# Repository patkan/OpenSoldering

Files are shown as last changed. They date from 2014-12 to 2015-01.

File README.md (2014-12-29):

OpenSoldering
=============

###Kurzbeschreibung
OpenSource Lötstation mit (hoffentlich mal) Unterstützung für verschiedene JBC-, Weller- und Ersa-Lötkolben

###Aufbau
Modular. Kommunikation über RS485 mit dem SB9-Bussystem

###Ziel
eine OpenSource Lötstation mit Basisstation und einzelnen Satellitenstationen, die jeweils ein Lötgerät (Kolben, Zange, Pinzette) ansteuern. Auch geeignet für Gruppen oder Werkstätten, die mehrere Lötplätze brauchen.

###Status Quo
- Modul für den JBC-Lötkolben T245A in Entwicklung.
- Thermospannung im Arbeitspunkt für C245 Kartusche 4,2mV; Aufnahme der Kennlinie fehlt noch.

###TODOs
- Aufbau und ausführliche Tests am Lötkolben, Programmierung der PI-Regelung mit Vorsteuerung, (vermutlich kein PID-Konzept nötig) und Bau der Kontrollstation.
- Planung für ein Weller-Modul für die modernen Lötspitzen des WXMP-Lötkolbens, die einen einfachen und günstigen Lötkolben versprechen.
- Planung der Kontrollstation:
	* Display: OLED? gLCD?
	* Eingabe: Drehknopf? Touchscreen?
	* zusätzliche Konnektivität: IoT? Bluetooth? Lötrauchabsaugung?
	* Reglerprofile: Optimierung auf Ausregelzeit/minimale Überschwingung?

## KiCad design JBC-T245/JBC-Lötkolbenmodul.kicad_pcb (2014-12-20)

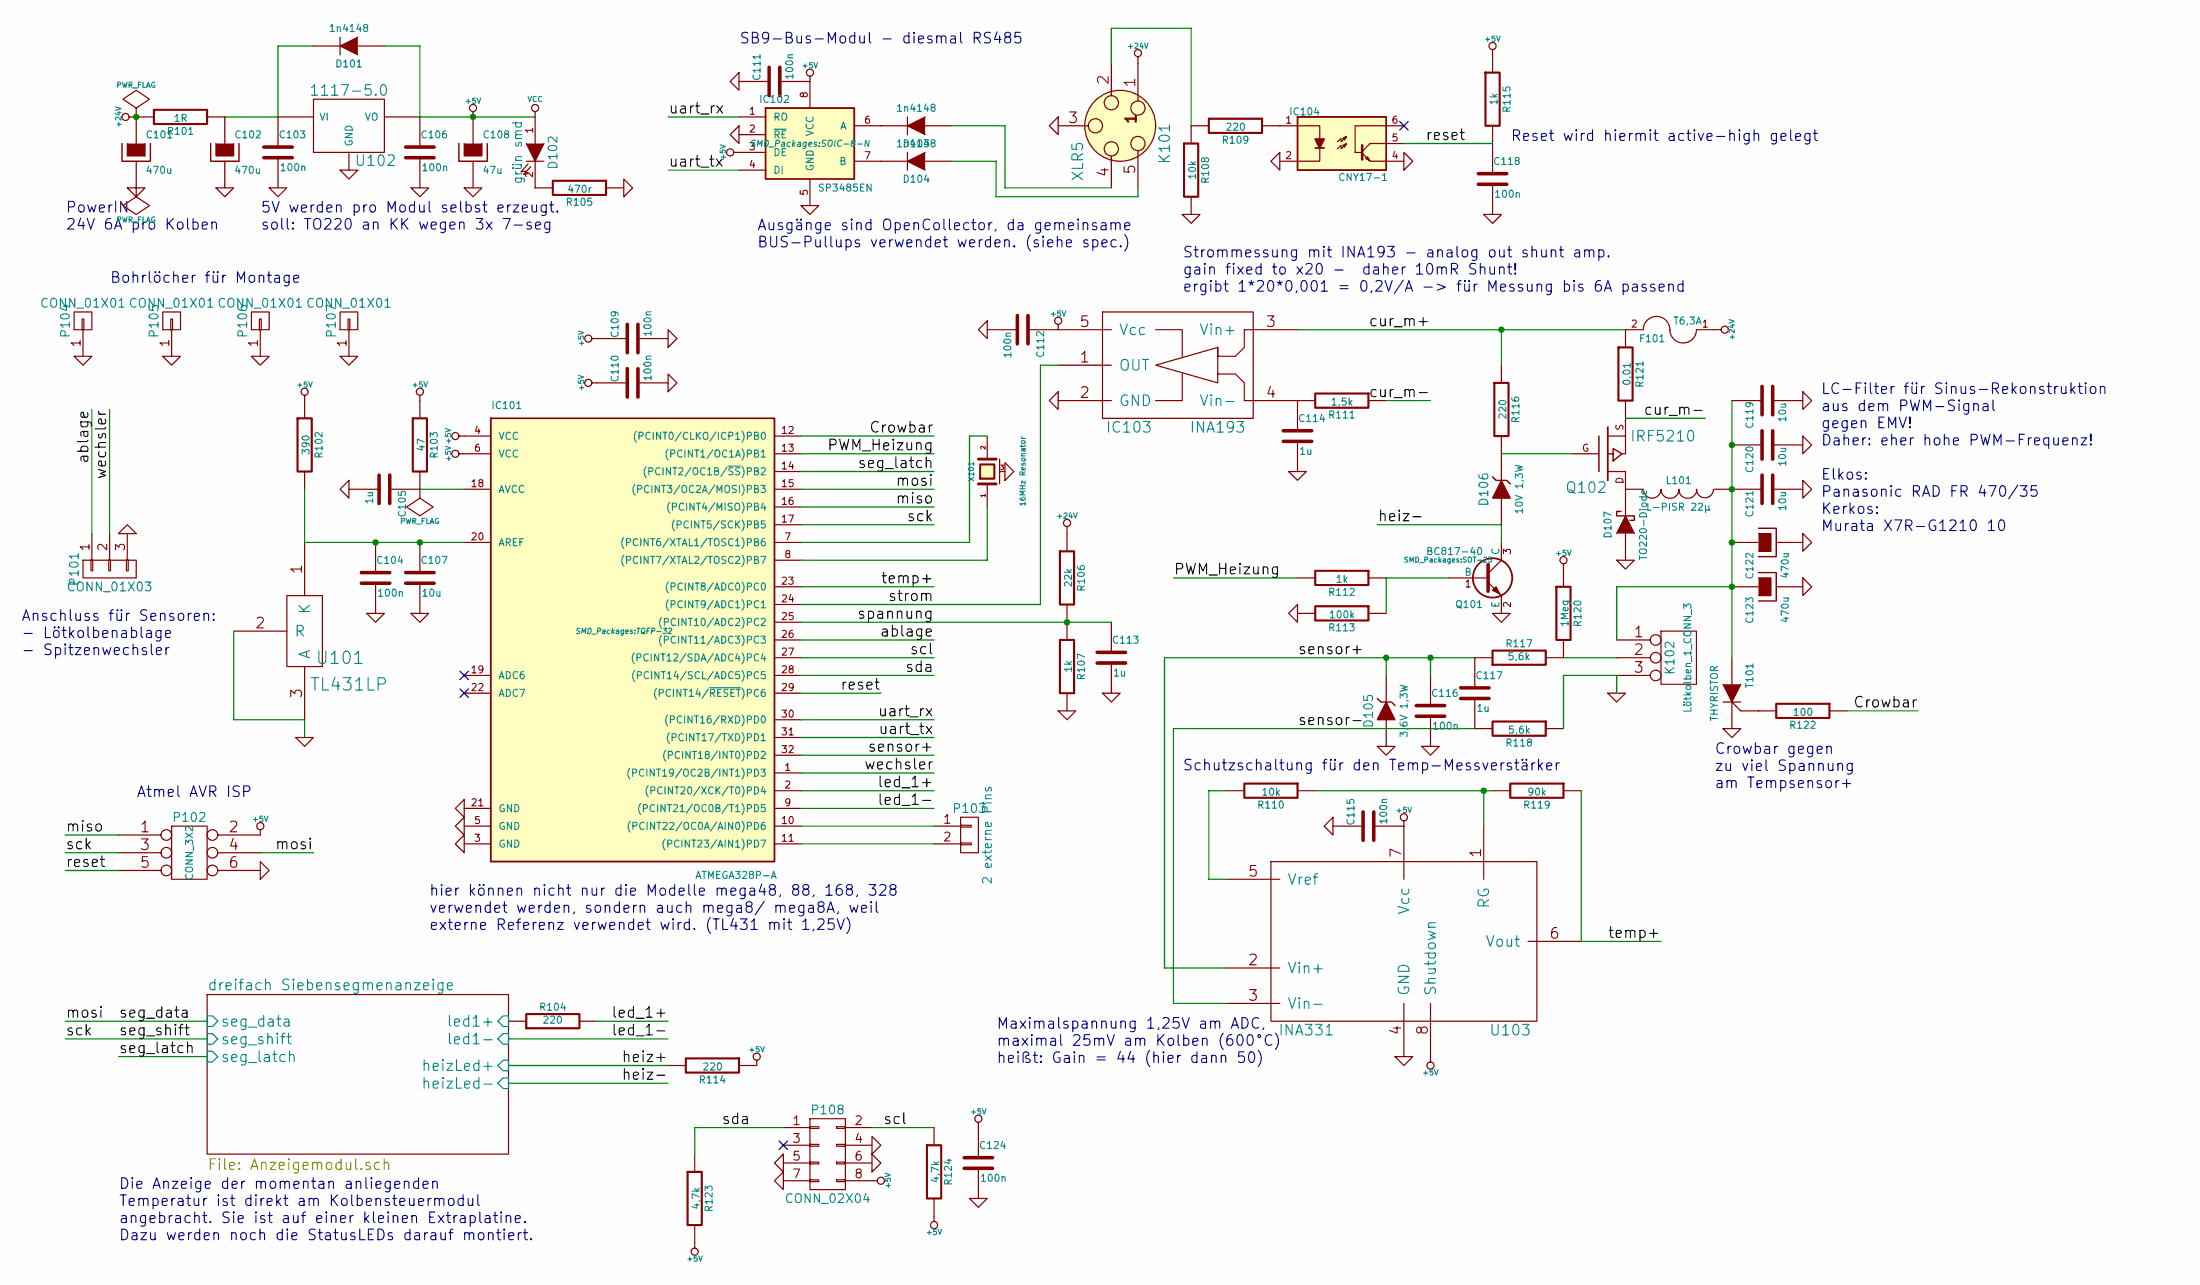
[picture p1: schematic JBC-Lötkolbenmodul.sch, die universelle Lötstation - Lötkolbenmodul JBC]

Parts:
C101, C102, C122, C123: 470u; Elko_vert_DM8_RM3-5_CopperClear
C103, C104, C106, C109, C110, C111, C112, C115, C116, C118, C124: 100n; C_0805
C105, C113, C114, C117: 1u; C_0805
C107: 10u; C_0805
C108: 47u; C_1210
C119, C120, C121: 10u; C_1210
D101, D103, D104: 1n4148; Diode-MiniMELF_Standard
D102: grün smd; LED-0805
D105: 3,6V 1,3W; Diode_DO-41_SOD81_Horizontal_RM10
D106: 10V 1,3W; Diode_DO-41_SOD81_Horizontal_RM10
D107: TO220-Diode; TO-220_Neutral123_Vertical
F101: T6,3A; Fuseholder5x20_Horizontal_closed_Bulgin_FX0457
IC101: ATMEGA328P-A; TQFP-32
IC102: SP3485EN; SOIC-8-N
IC103: INA193; SOT-23-5
IC104: CNY17-1; DIP-6__300_ELL
K101: XLR5; Pin_Header_Straight_1x05
K102: Lötkolben_1_CONN_3; Pin_Header_Straight_1x03
L101: L-PISR 22µ; L_Fastron_PISR
P101: CONN_01X03; Pin_Header_Straight_1x03
P102: CONN_3X2; Pin_Header_Straight_2x03
P103: 2 externe Pins; Pin_Header_Straight_1x02
P104, P105, P106, P107: CONN_01X01; 1pin
P108: CONN_02X04; SOIC-8-N
Q101: BC817-40; SOT-23
Q102: IRF5210; DPAK-3_GDS
R101: 1R; R_0603
R102: 390; R_0603
R103: 47; R_0603
R104, R109, R114, R116: 220; R_0603
R105: 470r; R_0603
R106: 22k; R_0603
R107, R112, R115: 1k; R_0603
R108, R110: 10k; R_0603
R111: 1,5k; R_0603
R113: 100k; R_0603
R117, R118: 5,6k; R_0603
R119: 90k; R_0603
R120: 1Meg; R_0603
R121: 0,01; R_1210
R122: 100; R_0603
R123, R124: 4,7k; R_0603
T101: THYRISTOR; TO-220_Neutral123_Vertical
U101: TL431LP; SOIC-8-N
U102: 1117-5.0; TO-220_Neutral123_Vertical
U103: INA331; SSOP-8
X101: 16MHz Resonator; CerOsc_3,2x1,3

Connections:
+24V: C101.1, F101.1, K101.1, R101.2, R106.1
/Crowbar: IC101.12 ((PCINT0/CLKO/ICP1)PB0), R122.1
/PWM_Heizung: IC101.13 ((PCINT1/OC1A)PB1), R112.2
/ablage: IC101.26 ((PCINT11/ADC3)PC3), P101.1
/cur_m+: F101.2, IC103.3 (Vin+), R116.1, R121.1
/cur_m-: Q102.S, R111.1, R121.2
/dreifach Siebensegmenanzeige/heizLed+: R114.2; also elsewhere on the board
/dreifach Siebensegmenanzeige/heizLed-: D106.1 (A), Q101.3 (C); also elsewhere on the board
/dreifach Siebensegmenanzeige/led1+: R104.1; also elsewhere on the board
/dreifach Siebensegmenanzeige/led1-: IC101.9 ((PCINT21/OC0B/T1)PD5); also elsewhere on the board
/dreifach Siebensegmenanzeige/seg_data: IC101.15 ((PCINT3/OC2A/MOSI)PB3), P102.4; also elsewhere on the board
/dreifach Siebensegmenanzeige/seg_latch: IC101.14 ((PCINT2/OC1B/~SS~)PB2); also elsewhere on the board
/dreifach Siebensegmenanzeige/seg_shift: IC101.17 ((PCINT5/SCK)PB5), P102.3; also elsewhere on the board
/led_1+: IC101.2 ((PCINT20/XCK/T0)PD4), R104.2
/miso: IC101.16 ((PCINT4/MISO)PB4), P102.1
/reset: C118.1, IC101.29 ((PCINT14/~RESET~)PC6), IC104.5, P102.5, R115.2
/scl: IC101.27 ((PCINT12/SDA/ADC4)PC4), P108.2, R124.1
/sda: IC101.28 ((PCINT14/SCL/ADC5)PC5), P108.1, R123.1
/sensor+: C116.1, C117.1, D105.2 (K), IC101.32 ((PCINT18/INT0)PD2), R117.1, U103.2 (Vin+)
/sensor-: C117.2, R118.2, U103.3 (Vin-)
/spannung: C113.1, IC101.25 ((PCINT10/ADC2)PC2), R106.2, R107.1
/strom: IC101.24 ((PCINT9/ADC1)PC1), IC103.1 (OUT)
/temp+: IC101.23 ((PCINT8/ADC0)PC0), R119.1, U103.6 (Vout)
/uart_rx: IC101.30 ((PCINT16/RXD)PD0), IC102.1 (RO)
/uart_tx: IC101.31 ((PCINT17/TXD)PD1), IC102.4 (DI)
/wechsler: IC101.1 ((PCINT19/OC2B/INT1)PD3), P101.2
unnamed: C102.1, C103.1, D101.2 (K), R101.1, U102.VI
unnamed: C104.1, C107.1, IC101.20 (AREF), R102.2, U101.1 (K)
unnamed: C105.1, IC101.18 (AVCC), R103.2
unnamed: C114.1, IC103.4 (Vin-), R111.2
unnamed: C119.1, C120.1, C121.1, C122.1, C123.1, K102.1, L101.1, T101.A
unnamed: D102.2 (K), R105.2
unnamed: D103.1 (A), K101.4 (P3)
unnamed: D103.2 (K), IC102.6 (A)
unnamed: D104.1 (A), K101.5
unnamed: D104.2 (K), IC102.7 (B)
unnamed: D106.2 (K), Q102.G, R116.2
unnamed: D107.2 (K), L101.2, Q102.D
unnamed: IC101.7 ((PCINT6/XTAL1/TOSC1)PB6), X101.2
unnamed: IC101.8 ((PCINT7/XTAL2/TOSC2)PB7), X101.1
unnamed: IC101.10 ((PCINT22/OC0A/AIN0)PD6), P103.1
unnamed: IC101.11 ((PCINT23/AIN1)PD7), P103.2
unnamed: IC104.1, R109.1
unnamed: K101.2, R108.1, R109.2
unnamed: K102.2 (PM), R117.2, R120.2
unnamed: Q101.1 (B), R112.1, R113.1
unnamed: R110.1, R119.2, U103.1 (RG)
unnamed: R110.2, U103.5 (Vref)
unnamed: R122.2, T101.G

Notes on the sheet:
Atmel AVR ISP
PowerIN 24V 6A pro Kolben
Crowbar gegen zu viel Spannung am Tempsensor+
Schutzschaltung für den Temp-Messverstärker
SB9-Bus-Modul - diesmal RS485
Ausgänge sind OpenCollector, da gemeinsame BUS-Pullups verwendet werden. (siehe spec.)
5V werden pro Modul selbst erzeugt. soll: TO220 an KK wegen 3x 7-seg
Anschluss für Sensoren: - Lötkolbenablage - Spitzenwechsler
LC-Filter für Sinus-Rekonstruktion aus dem PWM-Signal gegen EMV! Daher: eher hohe PWM-Frequenz! Elkos: Panasonic RAD FR 470/35 Kerkos: Murata X7R-G1210 10
Strommessung mit INA193 - analog out shunt amp. gain fixed to x20 - daher 10mR Shunt! ergibt 1*20*0,001 = 0,2V/A -> für Messung bis 6A passend
Die Anzeige der momentan anliegenden Temperatur ist direkt am Kolbensteuermodul angebracht. Sie ist auf einer kleinen Extraplatine. Dazu werden noch die StatusLEDs darauf montiert.
Maximalspannung 1,25V am ADC, maximal 25mV am Kolben (600°C) heißt: Gain = 44 (hier dann 50)
Reset wird hiermit active-high gelegt
hier können nicht nur die Modelle mega48, 88, 168, 328 verwendet werden, sondern auch mega8/ mega8A, weil externe Referenz verwendet wird. (TL431 mit 1,25V)
Bohrlöcher für Montage

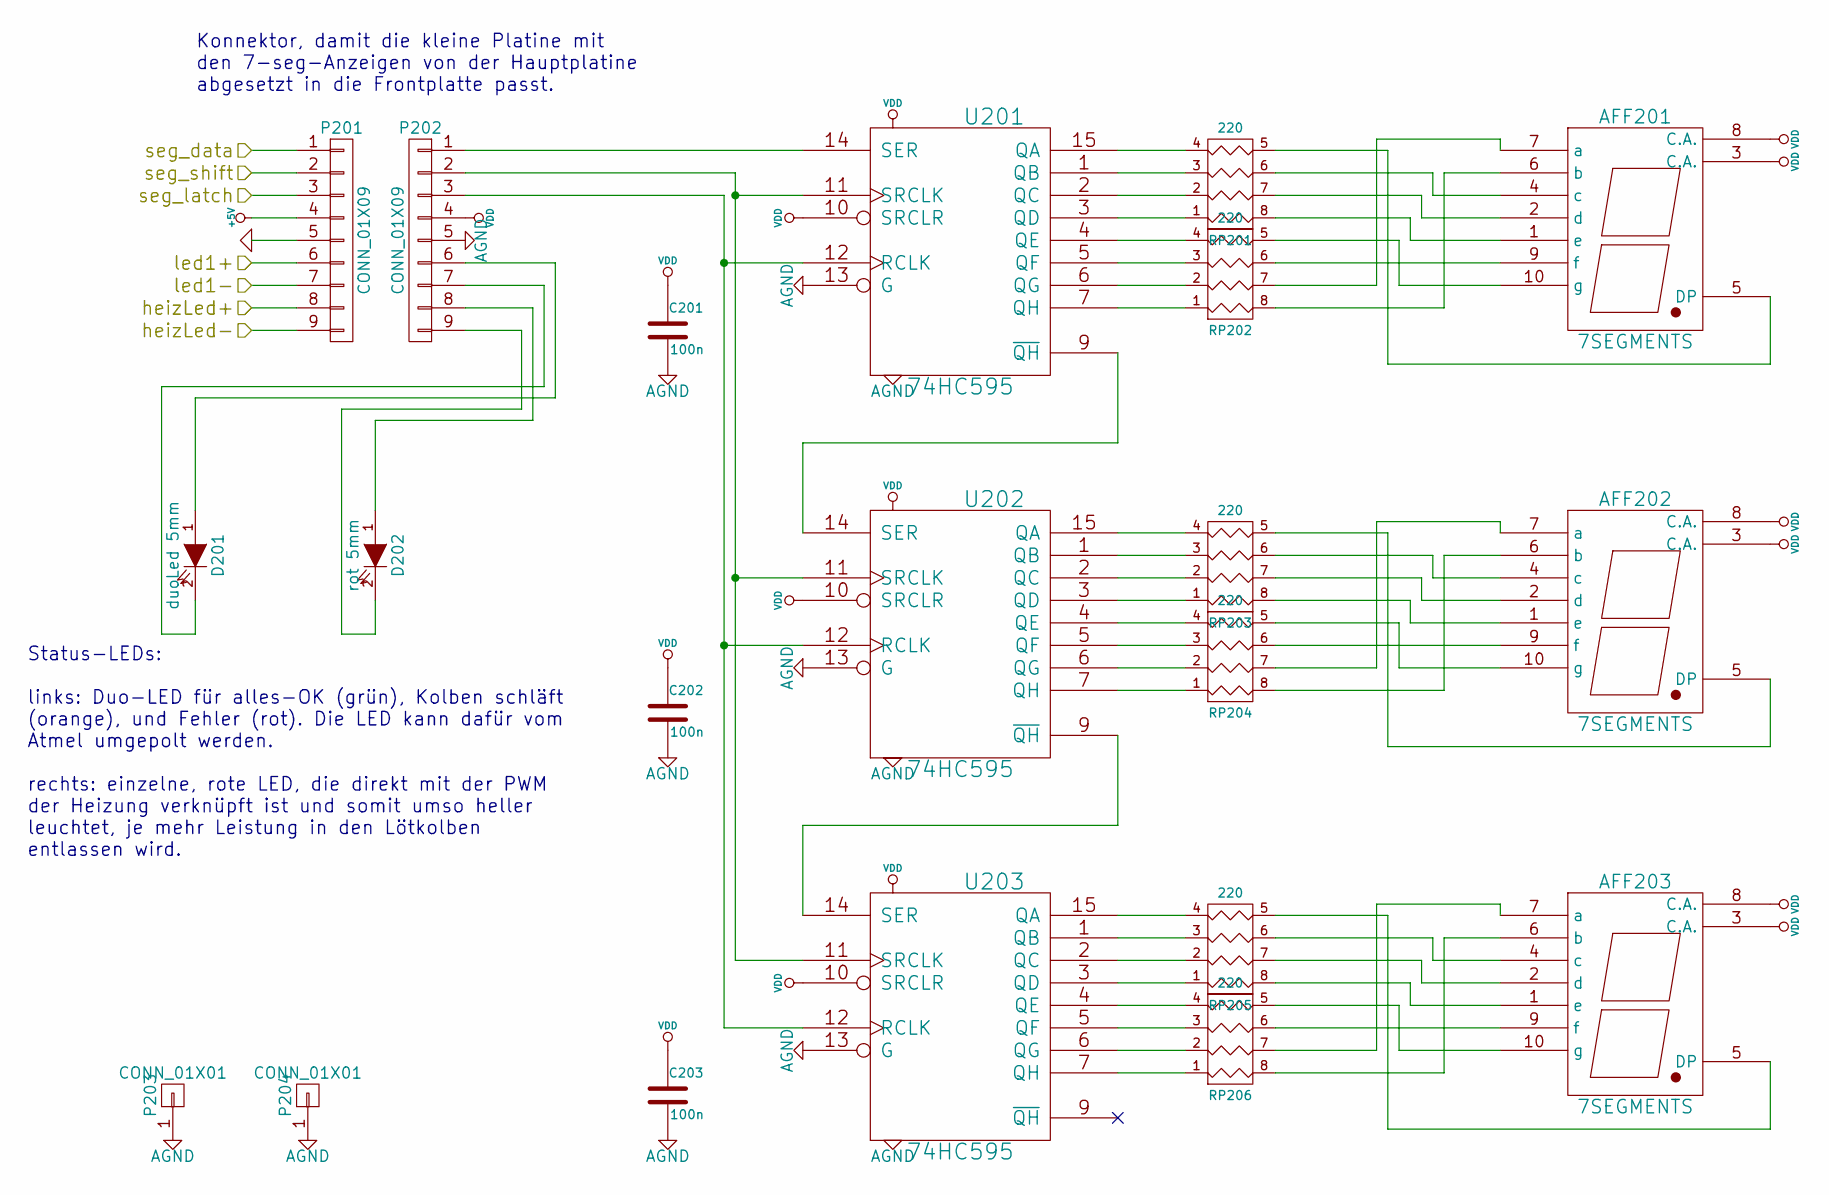
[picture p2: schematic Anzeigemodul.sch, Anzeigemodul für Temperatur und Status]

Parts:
AFF201, AFF202, AFF203: 7SEGMENTS; DIP-10__300_ELL
C201, C202, C203: 100n; C_0805
D201: duoLed 5mm; LED-5MM
D202: rot 5mm; LED-5MM
P201: CONN_01X09; Pin_Header_Straight_1x09
P202: CONN_01X09; Pin_Header_Angled_1x09
P203, P204: CONN_01X01; 1pin
RP201, RP202, RP203, RP204, RP205, RP206: 220; R_Cat16-4
U201, U202, U203: 74HC595; SO-16-N

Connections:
/dreifach Siebensegmenanzeige/heizLed+: P201.8; also elsewhere on the board
/dreifach Siebensegmenanzeige/heizLed-: P201.9; also elsewhere on the board
/dreifach Siebensegmenanzeige/led1+: P201.6; also elsewhere on the board
/dreifach Siebensegmenanzeige/led1-: P201.7; also elsewhere on the board
/dreifach Siebensegmenanzeige/seg_data: P201.1; also elsewhere on the board
/dreifach Siebensegmenanzeige/seg_latch: P201.3; also elsewhere on the board
/dreifach Siebensegmenanzeige/seg_shift: P201.2; also elsewhere on the board
unnamed: AFF201.1 (e), RP201.8 (R1)
unnamed: AFF201.2 (d), RP201.7 (R2)
unnamed: AFF201.4 (c), RP201.6 (R3)
unnamed: AFF201.5 (DP), RP201.5 (R4)
unnamed: AFF201.6 (b), RP202.8 (R1)
unnamed: AFF201.7 (a), RP202.7 (R2)
unnamed: AFF201.9 (f), RP202.6 (R3)
unnamed: AFF201.10 (g), RP202.5 (R4)
unnamed: AFF202.1 (e), RP203.8 (R1)
unnamed: AFF202.2 (d), RP203.7 (R2)
unnamed: AFF202.4 (c), RP203.6 (R3)
unnamed: AFF202.5 (DP), RP203.5 (R4)
unnamed: AFF202.6 (b), RP204.8 (R1)
unnamed: AFF202.7 (a), RP204.7 (R2)
unnamed: AFF202.9 (f), RP204.6 (R3)
unnamed: AFF202.10 (g), RP204.5 (R4)
unnamed: AFF203.1 (e), RP205.8 (R1)
unnamed: AFF203.2 (d), RP205.7 (R2)
unnamed: AFF203.4 (c), RP205.6 (R3)
unnamed: AFF203.5 (DP), RP205.5 (R4)
unnamed: AFF203.6 (b), RP206.8 (R1)
unnamed: AFF203.7 (a), RP206.7 (R2)
unnamed: AFF203.9 (f), RP206.6 (R3)
unnamed: AFF203.10 (g), RP206.5 (R4)
unnamed: D201.1 (A), P202.6
unnamed: D201.2 (K), P202.7
unnamed: D202.1 (A), P202.8
unnamed: D202.2 (K), P202.9
unnamed: P202.1, U201.14 (SER)
unnamed: P202.2, U201.11 (SRCLK), U202.11 (SRCLK), U203.11 (SRCLK)
unnamed: P202.3, U201.12 (RCLK), U202.12 (RCLK), U203.12 (RCLK)
unnamed: RP201.1, U201.3 (QD)
unnamed: RP201.2, U201.2 (QC)
unnamed: RP201.3, U201.1 (QB)
unnamed: RP201.4, U201.15 (QA)
unnamed: RP202.1, U201.7 (QH)
unnamed: RP202.2, U201.6 (QG)
unnamed: RP202.3, U201.5 (QF)
unnamed: RP202.4, U201.4 (QE)
unnamed: RP203.1, U202.3 (QD)
unnamed: RP203.2, U202.2 (QC)
unnamed: RP203.3, U202.1 (QB)
unnamed: RP203.4, U202.15 (QA)
unnamed: RP204.1, U202.7 (QH)
unnamed: RP204.2, U202.6 (QG)
unnamed: RP204.3, U202.5 (QF)
unnamed: RP204.4, U202.4 (QE)
unnamed: RP205.1, U203.3 (QD)
unnamed: RP205.2, U203.2 (QC)
unnamed: RP205.3, U203.1 (QB)
unnamed: RP205.4, U203.15 (QA)
unnamed: RP206.1, U203.7 (QH)
unnamed: RP206.2, U203.6 (QG)
unnamed: RP206.3, U203.5 (QF)
unnamed: RP206.4, U203.4 (QE)
unnamed: U201.9 (~QH), U202.14 (SER)
unnamed: U202.9 (~QH), U203.14 (SER)

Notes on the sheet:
Konnektor, damit die kleine Platine mit den 7-seg-Anzeigen von der Hauptplatine abgesetzt in die Frontplatte passt.
Status-LEDs: links: Duo-LED für alles-OK (grün), Kolben schläft (orange), und Fehler (rot). Die LED kann dafür vom Atmel umgepolt werden. rechts: einzelne, rote LED, die direkt mit der PWM der Heizung verknüpft ist und somit umso heller leuchtet, je mehr Leistung in den Lötkolben entlassen wird.

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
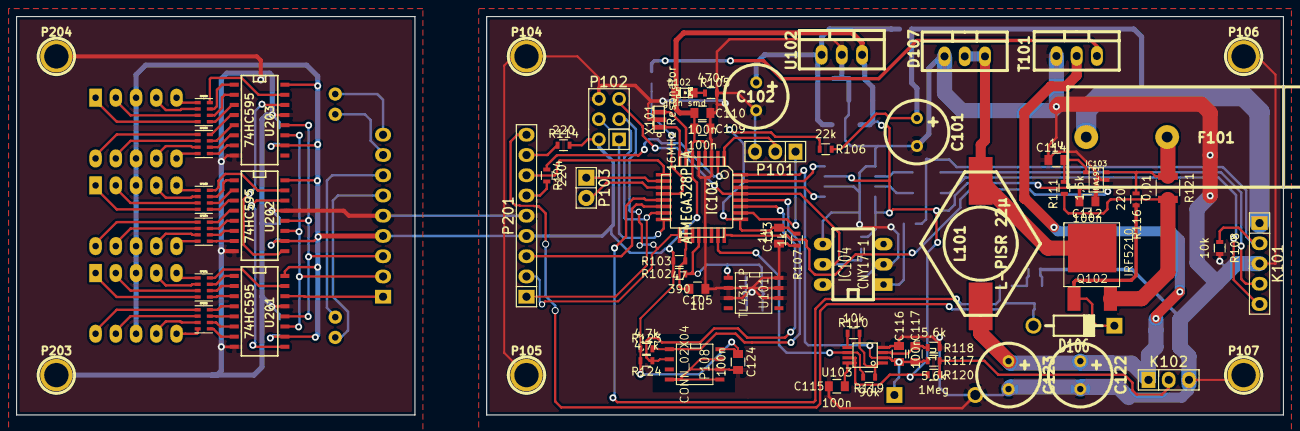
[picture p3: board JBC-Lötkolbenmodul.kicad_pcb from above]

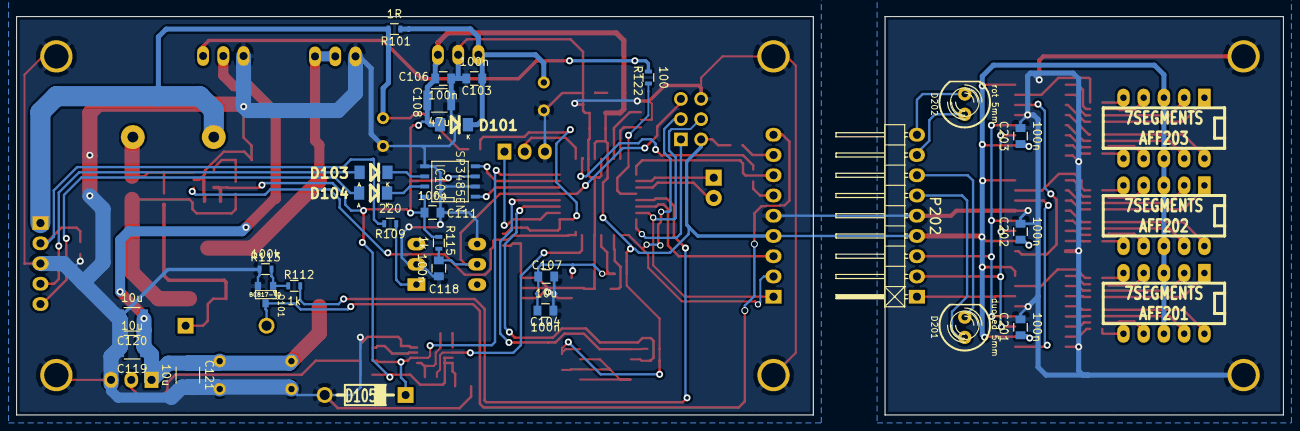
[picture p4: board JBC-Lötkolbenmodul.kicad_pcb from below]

Board: 2 copper layers, 159.0 x 50.0 mm, 99 parts (31 on the bottom side), 108 nets.

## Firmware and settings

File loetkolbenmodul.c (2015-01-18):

/*
 *    Filename: loetkobenmodul.c
 *     Version: 0.0.4
 * Description: Ansteuerung eines JBC T245A Lötkolbens
 *     License: GPLv3 or later
 *     Depends: global.h, io.h, interrupt.h, sb9, i2c
 *
 *      Author: Copyright (C) Philipp Hörauf
 *        Date: 2014-12-19
 *
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
 */

#include "definitionen.h"
#include "pid.c"
extern volatile float kp, ki, kd; //TODO --> das hier soll noch weg


void setKolbenPower (float sollwert) {
	// 16bit Timer1 auf FastPWM, Ausgang OC1A sei Lötkolben.
}

// Der ADC wird interruptgesteuert
volatile uint8_t counter = 0; // für Berechnung von Heizleistung und Temperatur des Lötkolbens
volatile float leistung = 0, rawtemp = 0, spitzentemp = 0;
volatile uint16_t heizstrom = 0, eingangsspannung = 0; // U in mV, I in mA
volatile uint16_t solltemperatur = 0, platinentemperatur = 0;

//volatile float ki = 1, kp = 1, kd = 1; // werden bereits in pid.c deklariert --> Zugriff sollte am besten nur über setTunings erfolgen

ISR (TIMER0_OVF_vect, ISR_BLOCK) {
	ADMUX = ADMUX & 0b11100000; // lösche selektiv die MUX-Bits
	ADMUX |= (counter%3); // setze ADC-Kanal neu
	ADCSRA |= 1<<ADSC; // start conversion

	// Auslesung der Temperatur des LM75-Sensors
	static uint8_t i2cAuslesung = 0;
	if (i2cAuslesung == 123) { // es sind ca 500 ms vergangen
		platinentemperatur = (i2cRxLm75 (0b1001000)) /16; // erst mal in ganzen °C
		i2cAuslesung = 0;
	} else {
		i2cAuslesung++;
	}


	// PID Regler muss auch hier drin arbeiten, da er mit gleichem Zeitabstand
	// ausgeführt wird, wie der ADC. bzw. mit 1/3 der ADC Frequenz.

	/* Erklärung der Ausgangsübertragungsfunktion und der Regelung:
	

	* 
	* yk	= Ausgangswert des Integrators
	* ek	= Differenz der Temperatur vom Sollwert (+ => zu kalt)
	* ki	= I-Verstärungswert
	* kr	= Reglerverstärkung
	* 
	* Eine Vorsteuerung hat wegen der stark wechselnden Lastsituationen
	* keinen großen Sinn und wird daher weggelassen.

	*
	* Die Störung Z(s) wirkt direkt auf die Temperatur der Lötspitze ein, sie
	* ist der Wärmestrom von der Lötspitze in die Luft (Standardfall) oder in
	* die Lötstelle (Regler muss eingreifen)
	*/


	//TODO: dies ist der neue Aufruf für die externe PID-Funktion
	//float yk;
	//yk = pid_compute(spitzentemp, solltemperatur);



	
	// Regler (Konzept: PI)
	float ek = solltemperatur - rawtemp;
	static float yk;
	yk += (ki * ek);
	

	// Weitergabe an Ausgabefunktion:
	setKolbenPower (yk + (kp * ek));
}

// ADC Conversion Complete Interrupt
// ADC0 = Temperatur, ADC1 = Heizstrom, ADC2 = Systemspannung
// Die Werte können noch kalibriert werden, allerdings nicht zur Laufzeit.

#define REFERENZ 1			// externe Referenz, 1250mV also 1,2207mV pro STEP
#define ABWEICHUNG 0.220703125		// gemessene Abweichung in %/100 vom exakten Referenzspannungswert
#define MITTELWERTE 4
#define SPANNUNG_PRO_GRAD 1.00000	// Spannung am ADC pro Grad am Lötkolben
#define SPANNUNG_PRO_AMPERE 0.2		// Spannung am ADC pro Ampere das durch die Heizung fließt
#define SPANNUNG_PRO_VOLT 0.04347826	// Spannung am ADC pro Volt der Versorgungsspannung

ISR (ADC_vect, ISR_BLOCK) {
	// 	uartTxStrln("adc");
	// ADC-Auslesungen und Rechnung mit Gleitmittelwert über 4 Werte
	static uint16_t tabelle[3*MITTELWERTE]; // hier kommen die ADC-werte rein.
	uint16_t temp=0;
	tabelle[counter] = ADC; // fülle Tabelle mit ADC-Werten

// 	TODO: Formeln anpassen!!

	switch (counter%3) {
		case 0:
			// Achtung: die Lötspitze wird kaltstellenkompensiert (daher die Zusatzvariable)
			spitzentemp = spitzentemp*0.95 + (((float)((temp*REFERENZ)<<2)*ABWEICHUNG*SPANNUNG_PRO_GRAD) + platinentemperatur)*0.05;
			rawtemp = ((float)((tabelle[counter]*REFERENZ)<<2)*ABWEICHUNG*SPANNUNG_PRO_GRAD) + platinentemperatur;
			break;

		case 1:
			// Heizstrom wird ausgerechnet
			for(uint8_t i=0; i<MITTELWERTE; i++) {
				temp += tabelle[1 + 3*i];
			}
			heizstrom = (uint16_t)((float)((temp*REFERENZ)<<2)*ABWEICHUNG*SPANNUNG_PRO_AMPERE);
			break;

		case 2:
			// Eingangsspannung wird ausgerechnet
			for(uint8_t i=0; i<MITTELWERTE; i++) {
				temp += tabelle[2 + 3*i];
			}
			eingangsspannung = (uint16_t)((float)temp*ABWEICHUNG*SPANNUNG_PRO_VOLT);
			break;
	}
	counter++;
	if (counter == 3*MITTELWERTE) { // setze Counter zurück
		counter = 0;
	}
	leistung = ((float)heizstrom * (float)eingangsspannung) / 1000; // Leistung in Watt
}



int main(void) {

	// Allgemeine PIN- und PORT-Einstellungen
	DDRB = 1<<PB0 | 1<<PB1 | 1<<PB2 | 1<<PB3 | 1<<PB5;
	DDRD = 1<<PD1 | 1<<PD4 | 1<<PD5; // PD4 ist WS2812B Datenpin
	PORTC = 1<<PC3; // Pullup für Lötkolbenständerschalter
	PORTD = 1<<PD3; // Lötspitzenwechslerschalter

	delayms(100);

	spiInit();
	i2cInit();
	lm75Init();
// 	timerInit();
// 	uartInit();
	writeSegments(42);

	// Initialiserung der WS2812-StatusLED
	struct cRGB led[1];
	led[0].g=128;
	led[0].b=75;
	led[0].b=25;
	ws2812_setleds(led,1);

// 	sei(); // und es seien Interrupts :D


	delayus(10);
	i2cRxLm75Start(0b1001000);

	while(1) {
// 		i2cRxLm75Start(0b1001000);
// 		temp = i2cRxLm75 (0b1001000);
// 		writeSegments (i2cERR & 0xF8);
		writeSegments (platinentemperatur);
		delayms(100);
	}
	return 0;
}

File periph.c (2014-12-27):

// Initialisierungsfunktionen für die verschiedenen
// Peripheriekomponenten wie SPI, I2C, ADC, SB9, ...


//******************************************************
//	INIT Funktionen für Peripheriekomponenten
//******************************************************

void spiInit (void) {
	DDRB |= 1<<PB2 | 1<<PB3 | 1<<PB5;
	SPCR = 1<<SPE | 1<<MSTR; // SPI Master Mode, clock vollgas
	SPSR = 0;
}

void i2cInit (void) {
	// verwende natürlich auch hier VOLLGAS (400kHz Clockspeed)
	TWBR = 3;
	TWCR = 1<<TWEA | 1<<TWEN; // automatisch ACK
	TWSR = 1<<TWPS0; // prescaler = 4
}

void adcInit(void) {
	// Der ADC läuft mit 16e6 / 128 = 125kHz
	// bei 13 Zyklen pro Wandlung sind das 9,615ksps 
	ADMUX = 0; // Referenz auf externe Referenz
	ADCSRA = 1<<ADEN | 1<<ADSC | 1<<ADIE | 5<<ADPS0; // ADC an, Interrupt an, Prescaler=128
}

void timerInit(void) {
	// Timer/Counter0 kann nur Overflow-Interrupt. daher Prescaler auf 256
	// heißt: alle 4,08ms kommt ein Interrupt rein.
	TCCR0 = 1<<CS02; // Prescaler = 256
	TIMSK |= 1<<TOIE0; // Overflow Interrupt aktiv
	
	// Timer/Counter1 im PhaseCorrectPWM Modus verwenden. (Heizung an OC1A)
	TCCR1A = 1<<COM1A1 | 1<<WGM11 | 1<<WGM10; // PhaseCorrectPWM 10 Bit
	TCCR1B = 1<<CS11 | 1<<CS10; // Prescaler = 64
	OCR1A  = 0; // Lötkolben erst mal aus.
}



//******************************************************
//	Systemfunktionen und HAL
//******************************************************

uint8_t i2cERR = 0;
uint8_t i2cError (void) {
	i2cERR = TWSR;
	TWSR = 1<<TWPS0; // lösche alles außer der ersten beiden Bits
	return i2cERR;
}

void i2cDelay (void) {
	while (!(TWCR & (1<<TWINT))); // Warte, dass sich das TWINT-Bit setzt
}

void i2cStart (void) {
	// Start Condition
	TWCR = 1<<TWINT | 1<<TWSTA | 1<<TWEN;
	i2cDelay ();
	if ((TWSR & 0xF8) != TW_START) {
		i2cError();
	}
}

inline void i2cRestart (void) {
	i2cStart ();
}

void i2cStop (void) {
	// Stop Condition
	TWCR = 1<<TWINT | 1<<TWEN | 1<<TWSTO;
}

void i2cAdrTransmit (uint8_t daten) {
	TWDR = daten;
	TWCR = 1<<TWINT | 1<<TWEN;
	i2cDelay ();
	if ((TWSR & 0xF8) != TW_MT_SLA_ACK) {
		i2cError();
	}
}

void i2cDataTransmit (uint8_t daten) {
	TWDR = daten;
	TWCR = 1<<TWINT | 1<<TWEN;
	i2cDelay ();
	if ((TWSR & 0xF8) != TW_MT_DATA_ACK) {
		i2cError();
	}
}

uint8_t i2cReceive (void) {
	i2cDelay ();
	TWCR = 1<<TWINT | 1<<TWEN;
	i2cDelay ();
	uint8_t temp = TWDR;
	return temp;
}

void i2cTxByte (uint8_t adresse, uint8_t pointerwert, uint8_t daten) {
	i2cStart ();
	// adresse + writeEN-Bit
	i2cAdrTransmit (adresse<<1);
	// RAM-Adresse für Zieldaten senden
	i2cDataTransmit (pointerwert);
	// Daten senden
	i2cDataTransmit (daten);
	i2cStop ();
}

void lm75Init (void) {
	i2cTxByte (0b1001000, 1, 0b01111000);
}

void i2cRxLm75Start (uint8_t adresse) {
	i2cStart ();
	i2cAdrTransmit (adresse<<1);
	i2cDataTransmit (0); // selektiere Datenregister
	i2cStop ();
}

uint16_t i2cRxLm75 (uint8_t adresse) {
	// lesen geht folgendermaßen:
	// start
	// adresse + readbit senden
	// Register auslesen (16 bit)
	uint16_t temp = 0;
	i2cStart ();
	i2cAdrTransmit ((adresse<<1) | 1); // Read == 1. Bit gesetzt
	temp  = ((uint16_t)i2cReceive ()<<4); // obere 8 Bit
	temp |= (i2cReceive ()>>4); // untere 4 Bit
	// bei 12bit entspricht 1 LSB 1/16°C
	i2cStop ();
	return temp;
}

void adcStart(void) {
	ADCSRA |= 1<<ADSC;
}

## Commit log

2014-10-26 initial commit - erst mal das Projekt so online gestellt. philippH
    [Anzeigemodul.sch, JBC-Lötkolbenmodul.kicad_pcb, JBC-Lötkolbenmodul.sch]
2014-11-21 schutz für den Temperaturmesswandler verbessert
    [JBC-Lötkolbenmodul.kicad_pcb, JBC-Lötkolbenmodul.sch]
2014-12-19 Programm angefangen.
    [JBC-Lötkolbenmodul.kicad_pcb]
2014-12-20 fehlerhaftes footprint des 16MHz resonators. fixed. programm geht los.
    [JBC-Lötkolbenmodul.kicad_pcb]
2014-12-20 Planung Controllermodul und Thermospannung C245 Kartusche hinzugefügt.
2014-12-20 programm zählt ein bisschen. LED-anzeigen gehen also.
2014-12-20 gerberfiles in der gitignore datei verzeichnet.
2014-12-20 die Modularisierung zieht ein. inits und definitionen werden aus der main-Datei ausgelagert.
2014-12-21 anfang hardware i2c für den LM75 Tempsensor
    [JBC-Lötkolbenmodul.sch]
2014-12-21 ws2812 port und Pin korrekt eingestellt. i2c geht noch nicht.
2014-12-21 arbeit an der i2c Kommunikation. noch unfertig
2014-12-21 i2c weiter versuchen :(
2014-12-21 änderungen i2c. noch keine lesefunktion, schreiben geht.
2014-12-21 temperatur des lm75 kann jetzt gelesen werden. leider noch nur 8 bit aber lesen geht schon mal.
2014-12-26 ADC und Timerfunktionen (tlw. aus server_lader übernommen) dazugefügt.
2014-12-26 anfang der regelung
2014-12-27 anfang der Regelung und änderung der ADC-steuerung auf Timer0 wegen nötigkeit des Timer1 für die PWM des Lötkolbens.
2014-12-27 timereinstellungen für timer1 gesetzt.
2014-12-28 teilweise Beschreibung der Regelung geschrieben.
2014-12-28 ADC-Auswertung incl. Kaltstellenkompensation dazugefügt. Faktor für Lötspitze muss allerdings noch angepasst werden
2014-12-31 BREAKS BUILD: loetkolbemodul.c auf pid-Regler vorbereitet
2015-01-07 BUILDS AGAIN; rauliche Startimplementierung eines PID-Controllers; Datentypen sind noch Pfusch

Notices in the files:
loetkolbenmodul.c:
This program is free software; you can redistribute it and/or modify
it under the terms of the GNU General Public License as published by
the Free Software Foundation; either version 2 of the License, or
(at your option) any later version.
